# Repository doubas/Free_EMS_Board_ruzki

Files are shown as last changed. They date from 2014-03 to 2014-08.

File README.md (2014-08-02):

# FreeEMS Board 40 for FreeEMS

### Introduction

The aim of the FreeEms Board 40 is to provided a simple and small prototyping board for use with the FreeEms firmware but with the same pinout as the MegaSquirt-II daughterboard has. The FreeEms Board 40 is not mentioned to be a 1:1 replacement for the Megasquirt-II daughterboard. In comparison with the Megasquirt-II daughterboard the FreeEMS Baord 40 misses the IAC Idle Valve driver and has already pin 40 and 39 connected to the MCU (3rd and 4th injector), also know as the sequential mod.

Please see forum.diyefi.org for the most up to date information and links for this project and all of the other aspects of the FreeEMS project.

### Specs

Core IO specs:

 * 1  Freescale MC9S12XDP512 MCU 40MHz main core speed, 80MHz XGATE coprocessor, 32KB RAM, 512KB flash
 * 2  RPM/Position inputs
 * 10 Standard analog inputs (IAT or MAT,CLT,TPS,O2,BRV,MAF,AAP,MAP,one spare input).
 * 5  Available Port P PWM ports (PP1-3,PP5,PP7) access to PP1 and PP3 through a spare 2x1 pin connector
 * 2  ignitor outputs 
 * 4  injector outputs
 * 1  Fuel Pump output.
 * 4  PA2-PA6 logic channels as replacement for IAC1, IAC2, PE0 and PE1
 * 2  Reference voltage input Vref and Vsyn
 * 1  Serial RX TX communication port
 * 1  CAN communication through a MCP2551
 * 1  Load jumper for loading the FreeEms firmware without BDM
 * 1  BDM connector 

PCB size is held small as possible but wider as the Megasquirt-II daughterboard. Board size is (60mm x 38mm).  Most of the components are SMD parts but not smaller than SMD 0805 so the parts can be soldered with some practice by hand. 

To maintain a small PCB size the FreeEms 40 Board uses bended male precision PCB contacts, these can be made by careful bending the standard precision PCB contacts. Already bended precision PCB contacts can be bought e.g.. „Fisher Elektronik MK 26 SMD“. It is recommended to solder this pins by using a 40 pin precision socket as fixation. 

### Status

These Board is in alpha status, it has been tested on a test bench but not yet in a car at driving conditions.

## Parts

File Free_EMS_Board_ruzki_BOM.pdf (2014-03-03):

Parts

Qty | Type | Value | Digikey.com | Conrad.de | Reference
1 | SMD

Resistor

0805

1%

1/4W | 120R | P120ADCT-‐ND
| | | | | R12
6 | SMD

Resistor

0805

1%

1/8W | 1k | P1.00KCCT-‐ND | R5,R6,R7,R8,R13,R14
1 | SMD

Resistor

0805

1%

1/8W | 2,43k | P2.43KCCT-‐ND | R15
1 | SMD

Resistor

0805

1%

1/8W | 3,3k | P3.30KCCT-‐ND | R4
6 | SMD

Resistor

0805

1%

1/8W | 10k | P10.0KCCT-‐ND | R1,R2,R3,R9,R10,R11
2 | SMD

Capacitor

0805

10%

X7R | 20pF | 399-‐8033-‐1-‐ND | C9,C10
1 | SMD

Capacitor

0805

10%

X7R | 680
| | pF | 399-‐1144-‐1-‐ND | | C7
1 | SMD

Capacitor

0805

10%

X7R | 6,8nF | 399-‐1157-‐1-‐ND | C8
1 | SMD

Capacitor

0805

10%

X7R | 100nF | 399-‐1170-‐1-‐ND | C15
9 | SMD

Capacitor

0805

10%

X7R | 220nF | 399-‐3491-‐1-‐ND | C1,C2,C5,C6,C11,C12,C13,C14,C15
2 | SMD

Capacitor

SMD-‐A

10%

| | 20V 10µF | 399-‐10138-‐1-‐ND | | C3,C4
1 | SMD

LED

0805

Blue | 160-‐1579-‐1-‐ND | D1
1 | MCU
MC9S12XDP512 | MC9S12XDP512VAL-‐ND | U1
1 | CAN
MCP2551 | MCP2551-‐I/SN-‐ND | IC1
1 | Crystal | 16
| | mHz | 535-‐10638-‐1-‐ND | | X1
2 | 20 pin

Fisher

Elektronik

MK

26

| | SMD/ 20/Z Pole
| | 40 | | 738470 -‐
| | | | 62 | P1
1 | 3x2 BDM
Connector | 3x2 | P3
1 | 2x1 Spare
Connector | 2x1 | P2
1 | 1x1 MAF
Connector | 1x1 | P4
1 | 2x1 Boot
Jumper | 2x1 | JP1

BOM

v0.1

## Free

## EMS

## Board

## Ruzki

## BOM

741119

-‐

62

I

## didn´t

## use

## the

## angled

## socket

board.

I

## took

a

## straight

## socket board

## and

## carefully

## bended

## the

pins.

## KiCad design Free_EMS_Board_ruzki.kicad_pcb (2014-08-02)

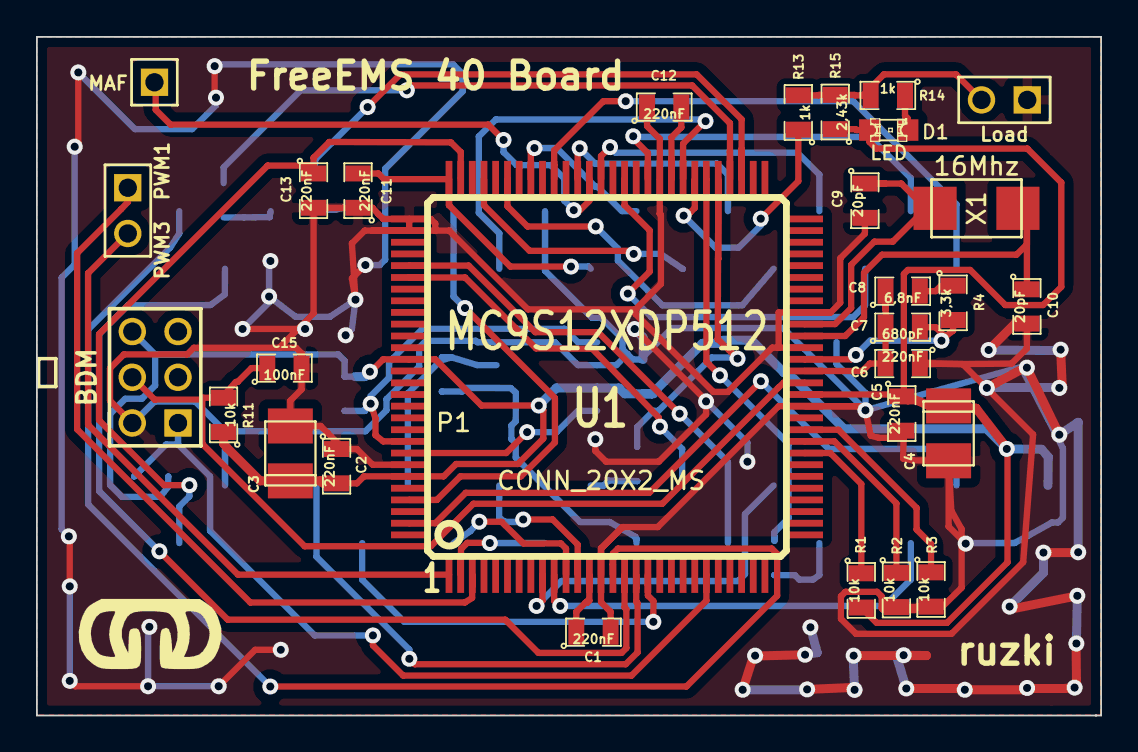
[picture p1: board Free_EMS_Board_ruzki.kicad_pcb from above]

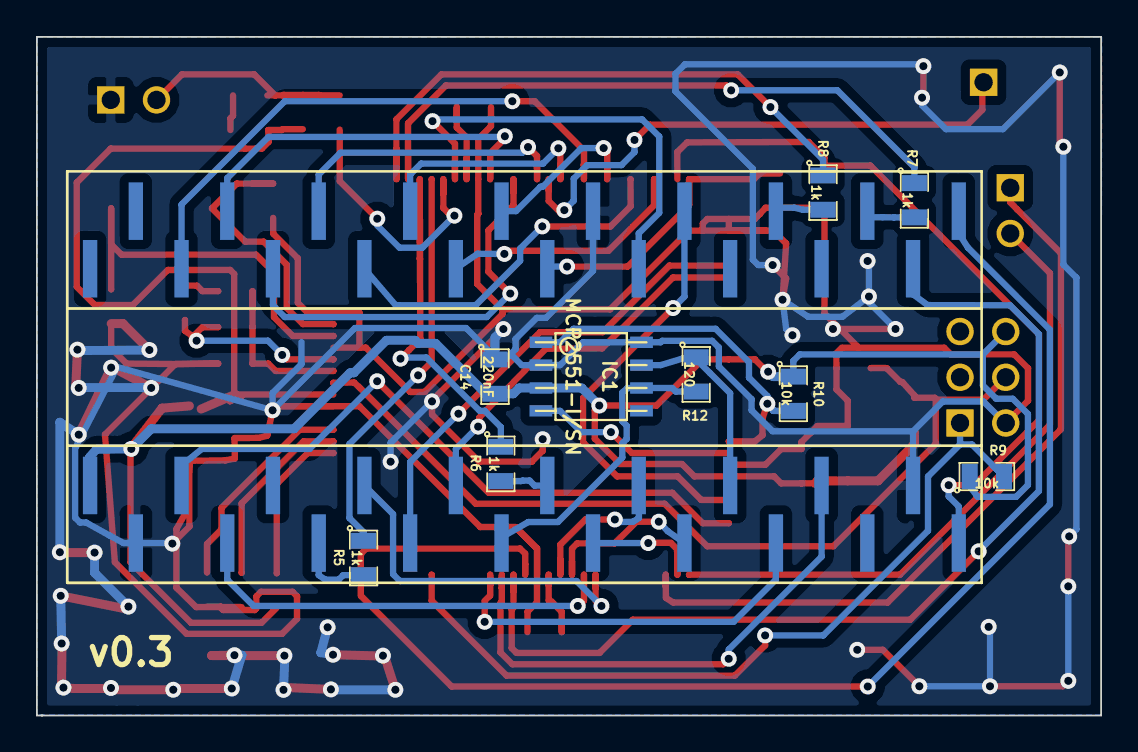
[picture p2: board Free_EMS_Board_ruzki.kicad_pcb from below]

Board: 2 copper layers, 59.1 x 37.7 mm, 39 parts (9 on the bottom side), 56 nets.

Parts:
BDM: CONN_3X2; pin_array_3x2
C1, C2, C5, C6, C11, C12, C13, C14: 220nF; SM0805
C3, C4: 10µF; c_tant_B
C7: 680pF; SM0805
C8: 6,8nF; SM0805
C9, C10: 20pF; SM0805
C15: 100nF; SM0805
D1: LED; LED-0805
IC1: MCP2551-I/SN; so-8
Load: JUMPER; PIN_ARRAY_2X1
MAF: CONN_1; PIN_ARRAY_1
P1: CONN_20X2_MS; SMD_20x2_Con
PWM3  PWM1: CONN_2; PIN_ARRAY_2X1
R1, R2, R3, R9, R10, R11: 10k; SM0805
R4: 3,3k; SM0805
R5, R6, R7, R8, R13, R14: 1k; SM0805
R12: 120; SM0805
R15: 2,43k; SM0805
U1: MC9S12XDP512; PQFP112
X1: 16Mhz; ABM3

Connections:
/MAF: MAF.1, U1.72
BKGD: BDM.1, R9.2, U1.23
Baro: P1.30, U1.77
Batt: P1.27, U1.79
Boost: P1.18, U1.111
CAM: P1.17, U1.10
CANH: IC1.7, P1.6, R12.1
CANL: IC1.6, P1.11, R12.2
CAN_RX: IC1.4, U1.105
CAN_TX: IC1.1, R10.2, U1.104
CLT: P1.25, U1.69
Crank: P1.14, U1.9
Fuel_Pump: P1.33, U1.64
GND: BDM.2, C1.2, C2.1, C3.2, C4.2, C5.2, C6.1, C9.2, C10.2, C11.1, C12.1, C13.2, C14.1, C15.2, IC1.2, IC1.8, Load.1, P1.2, P1.19, P1.32, R2.2, R3.2, U1.14, U1.40, U1.45, U1.48, U1.66, U1.85, U1.86, U1.106
IAC1A: P1.38, R7.2
IAC2A: P1.36, R8.2
IGN1/4: P1.7, U1.11
IGN2/3: P1.8, U1.12
Idle: P1.34, U1.109
Inj_1: P1.40, U1.15
Inj_2: P1.5, U1.18
Inj_3: P1.39, U1.16
Inj_4: P1.4, U1.17
MAP: P1.23, U1.75
MAT: P1.24, U1.67
unnamed: R2.1, U1.37
unnamed: R1.1, U1.36
unnamed: C12.2, U1.65
unnamed: C8.2, R4.1
unnamed: C7.2, R4.2, U1.44
unnamed: C1.1, U1.13
unnamed: D1.2, R14.1
unnamed: R13.1, U1.63
unnamed: Load.2, R13.2, R14.2, R15.2
unnamed: R5.1, U1.62
unnamed: R6.1, U1.61
unnamed: R7.1, U1.60
unnamed: R8.1, U1.59
unnamed: PWM3 PWM1.2, U1.1
unnamed: PWM3 PWM1.1, U1.3
unnamed: R3.1, U1.38
unnamed: C6.2, C7.1, C8.1, U1.43
unnamed: C10.1, U1.46, X1.1
unnamed: C9.1, U1.47, X1.2
PE0: P1.10, R6.2
PE1: P1.15, R5.2
RXD: P1.13, U1.89
Reset: BDM.4, C15.1, R11.2, U1.42
Sp_ADC: P1.29, U1.81
TPS: P1.26, U1.71
TXD: P1.12, U1.90
Tacho: P1.9, U1.2
VCC: BDM.6, C2.2, C3.1, C4.1, C5.1, C14.2, D1.1, IC1.3, P1.20, R1.2, R9.1, R10.1, R11.1, R15.1, U1.41, U1.97, U1.107
Vref: C11.2, P1.31, U1.84
Vsyn: C13.1, P1.1, U1.83
o2: P1.28, U1.73

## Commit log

2014-01-30 FreeEms Board v0.3
    version v0.3
    [Free_EMS_Board_ruzki.kicad_pcb, Free_EMS_Board_ruzki.sch]
2014-03-03 BOM
    Add Bill of Materials
    [Free_EMS_Board_ruzki_BOM.xls]
2014-03-03 BOM
    updated BOM
    [Free_EMS_Board_ruzki_BOM.xls]
2014-07-28 small changes
    small changes in the pcb file
2014-08-02 Create README.md
    new README based on the work of Andy Goss for the Jaguar PCB
2014-08-02 ground stitching ..
    added some ground stitching, moved c4 and c5 to be closer to the mcu,
    moved some components references, added a notch for orientation,
    preparation done for PCB manufacturing
    [Free_EMS_Board_ruzki.kicad_pcb]
